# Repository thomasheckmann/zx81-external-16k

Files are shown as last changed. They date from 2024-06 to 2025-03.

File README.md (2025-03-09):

# zx81-external-16k
Simple and compact external 16K RAM interface for the ZX81 with WRX compability. The interface is made using THT components, making it easy for everyone to make. The interface for now is only using 16K from the 62256 memory chip, using the other half 16K might be added on later version. I might also consider making a SMD version, making it even smaller in size :-)

| SCHEMA | PCB |
| --- | --- |
|||

## version 1.0
The PCB arrived, so I populated it with some components (all written on the silkscreen).



BOM for v1.0 (16K only)
- LED 3mm
- Resistor 470 Ohm
- Resistor 4K7 Ohm
- 2 x Ceramic capacitor 100nF, P2,54
- 2 x Diode 1N4148
- 74LS00
- RAM 62256 or similar
- ZX81 Edge Connector or my [ZX81 Bus Extender](https://github.com/thomasheckmann/zx81-bus-extender)
  
NOTE: WRX hi-res, to get full support for hi-res WRX a cercamic capacitor is needed between PIN 20 (CS) and GND. In this build with a KM62256ALP-10 a 1,2nF ceramic capacitor should be fitted. 

The value for the capacitor for different 62256 SRAM chips tested with [STARFIGHT](https://problemkaputt.de/starfigh.htm)

- KM62256ALP-10, 1.2nF

## version 1.1 - full 32K support, with data in the 32-48K area.
Most version for internal 32K RAM puts the extra 16K at the top, 48 to 64K - but this is not what most 32K program expects. The 32K programs I have found expect the 32K from 16K, which requires some extra logic - another issue with this configuration is that normaly the ROM is mirrored between 32 and 48K, which means the ROM has to be disabled when the ZX81 access this part of the memory. I also decided to change the diodes from 1N4148 to BAT85 as suggested in general for this type of usage.

A little prototyping based on the v1.0 board - and yes, 32K from adress 16384 is all good here tested with Beamrider that require 32K and WRX :-)
| <!---> | <!---> |
| --- | --- |
|||

Programs tested with success so far:
- [Beamrider](https://problemkaputt.de/beamride.htm), 32K and WRX graphics 
- [MaxDemo](https://demozoo.org/productions/159644/), 32K and WRX graphics (impressive 320x240 resolution)
- [Cross Snake](https://github.com/Fabrizio-Caruso/CROSS-LIB/releases/tag/XSnake2.0), 32K and WRX
- [Cross Chase](https://github.com/Fabrizio-Caruso/CROSS-LIB/releases/tag/WRX), 32K and WRX
- [Space Invaders](https://splintergu.itch.io/space-invaders-for-zx81-wrx), 32K and WRX

32K Programs NOT working - as they require internal modification in order to run M/C above 32K area.
- [The Crystal Frog](https://www.sinclairzxworld.com/viewtopic.php?t=334)

| <!---> | <!---> |
| --- | --- |
|||

BOM for v1.1 (32K, continously from adress 16384)
- LED 3mm
- Resistor 470 Ohm
- Resistor 4K7 Ohm
- Resistor 10K Ohm
- 2 x Ceramic capacitor 100nF, P2,54
- 1 x Ceramic capacitor 1,2nF, P2,54
- 2 x Diode BAT85
- 74LS00
- 74LS32
- RAM 62256 or similar
- ZX81 Edge Connector or my [ZX81 Bus Extender](https://github.com/thomasheckmann/zx81-bus-extender)

The interface has been tested with the following 32K SRAM chips, all running Beamrider perfectly.
- UM62256E-70LL
- HM62256BLP-10
- AS6C62256-55PCN

### Test using SYSINFO.P v0.02
This test program examines the memory configuration and reports this, 32K ram starting from address 0x4000 :-)



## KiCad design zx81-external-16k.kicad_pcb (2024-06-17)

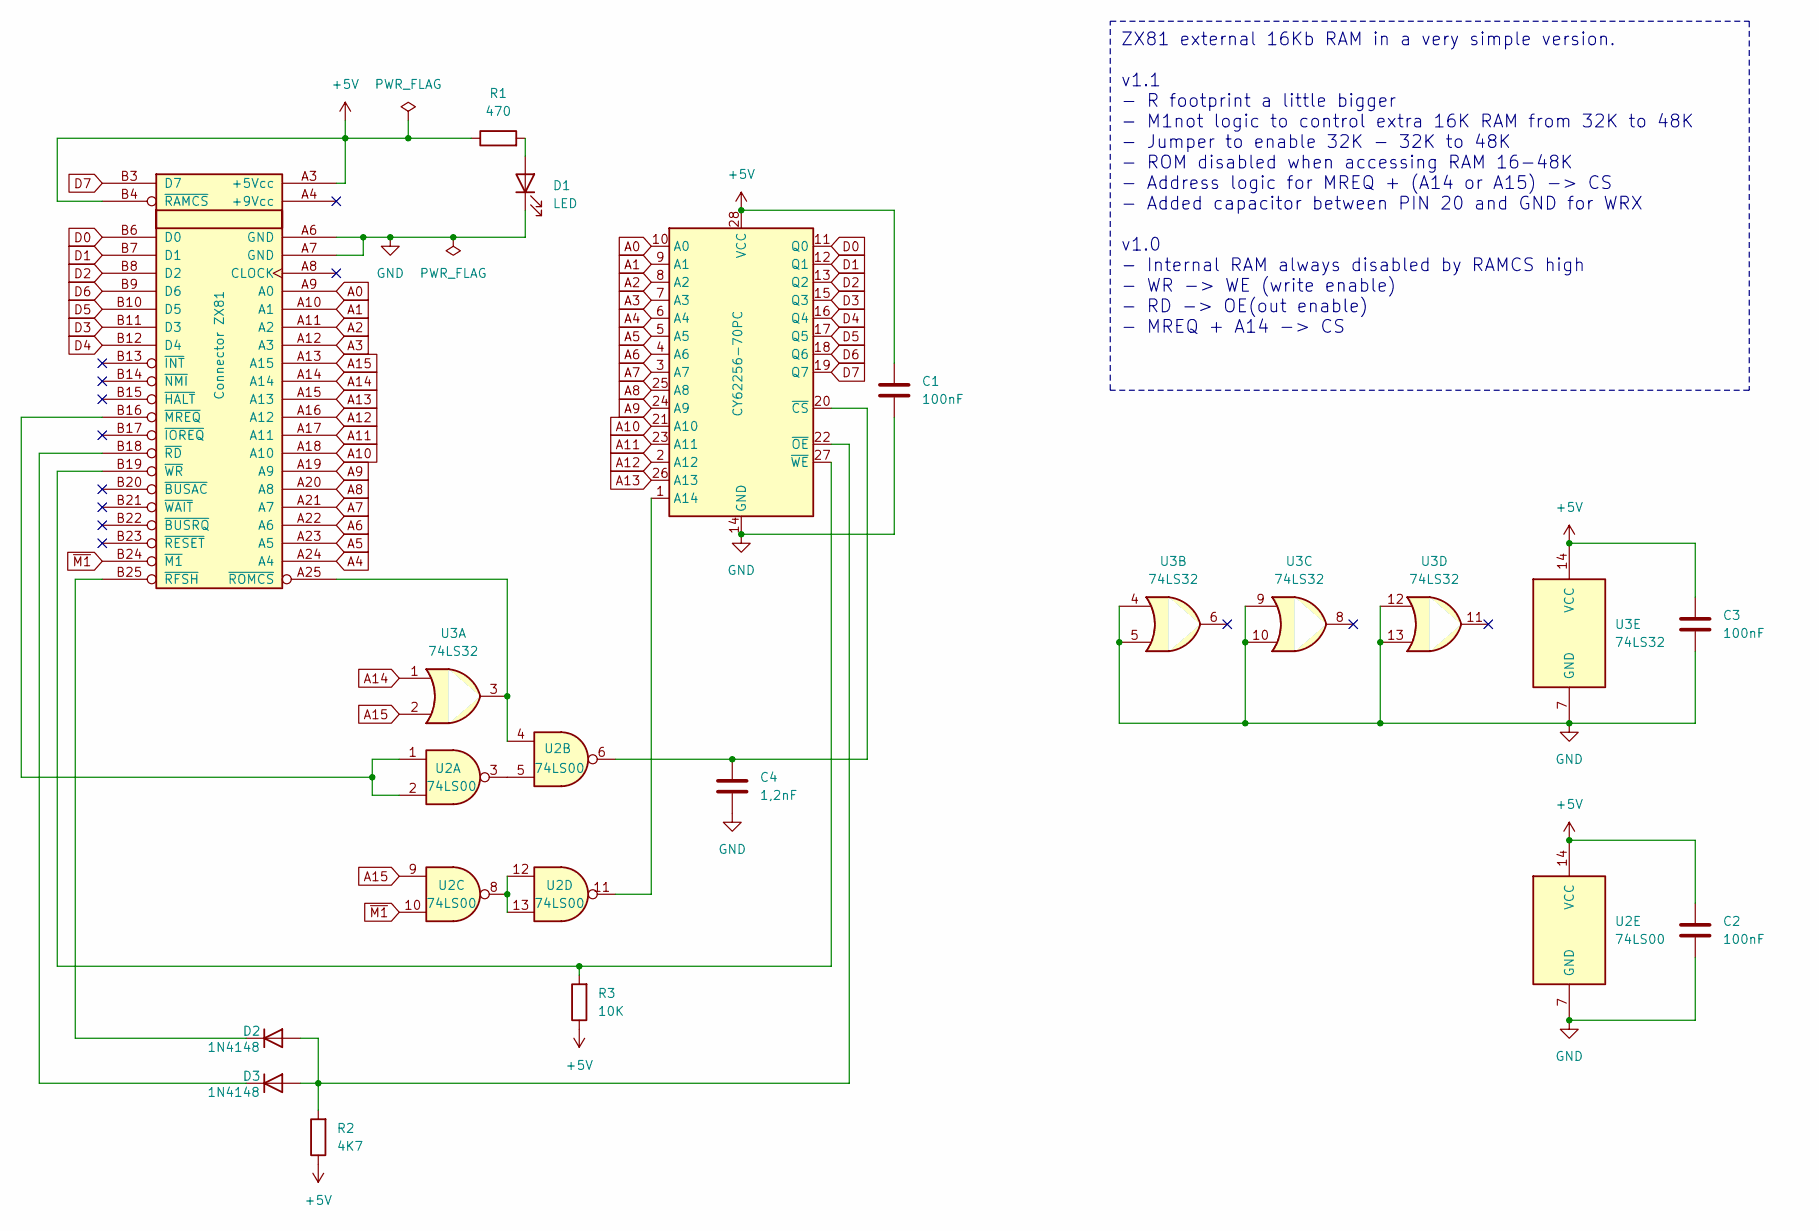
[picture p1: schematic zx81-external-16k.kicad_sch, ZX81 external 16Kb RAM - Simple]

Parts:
C1, C2, C3: 100nF; C_Disc_D3.0mm_W1.6mm_P2.50mm
C4: 1,2nF; C_Disc_D3.0mm_W1.6mm_P2.50mm
D1: LED; LED_D3.0mm
D2, D3: 1N4148; D_DO-35_SOD27_P7.62mm_Horizontal
J1: Connector ZX81; EDGE ZX81 BOTTOM
R1: 470; R_Axial_DIN0207_L6.3mm_D2.5mm_P10.16mm_Horizontal
R2: 4K7; R_Axial_DIN0207_L6.3mm_D2.5mm_P10.16mm_Horizontal
R3: 10K; R_Axial_DIN0207_L6.3mm_D2.5mm_P10.16mm_Horizontal
U1: CY62256-70PC; DIP-28_W15.24mm
U2: 74LS00; DIP-14_W7.62mm
U3: 74LS32; DIP-14_W7.62mm

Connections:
+5V: C1.1, C2.1, C3.1, J1.A3 (+5Vcc), J1.B4 (~RAMCS), R1.1, R2.1, R3.1, U1.28 (VCC), U2.14 (VCC), U3.14 (VCC)
A0: J1.A9 (A0), U1.10 (A0)
A1: J1.A10 (A1), U1.9 (A1)
A2: J1.A11 (A2), U1.8 (A2)
A3: J1.A12 (A3), U1.7 (A3)
A4: J1.A24 (A4), U1.6 (A4)
A5: J1.A23 (A5), U1.5 (A5)
A6: J1.A22 (A6), U1.4 (A6)
A7: J1.A21 (A7), U1.3 (A7)
A8: J1.A20 (A8), U1.25 (A8)
A9: J1.A19 (A9), U1.24 (A9)
A10: J1.A18 (A10), U1.21 (A10)
A11: J1.A17 (A11), U1.23 (A11)
A12: J1.A16 (A12), U1.2 (A12)
A13: J1.A15 (A13), U1.26 (A13)
A14: J1.A14, U3.1
A15: J1.A13 (A15), U2.9, U3.2
D0: J1.B6 (D0), U1.11 (Q0)
D1: J1.B7 (D1), U1.12 (Q1)
D2: J1.B8 (D2), U1.13 (Q2)
D3: J1.B11 (D3), U1.15 (Q3)
D4: J1.B12 (D4), U1.16 (Q4)
D5: J1.B10 (D5), U1.17 (Q5)
D6: J1.B9 (D6), U1.18 (Q6)
D7: J1.B3 (D7), U1.19 (Q7)
GND: C1.2, C2.2, C3.2, C4.2, D1.1 (K), J1.A6 (GND), J1.A7 (GND), U1.14 (GND), U2.7 (GND), U3.4, U3.5, U3.7 (GND), U3.9, U3.10, U3.12, U3.13
unnamed: D1.2 (A), R1.2
unnamed: D2.2 (A), D3.2 (A), R2.2, U1.22 (~OE)
unnamed: D2.1 (K), J1.B25 (~RFSH)
unnamed: D3.1 (K), J1.B18 (~RD)
unnamed: J1.B16 (~MREQ), U2.1, U2.2
unnamed: J1.A25 (~ROMCS), U2.4, U3.3
unnamed: J1.B19 (~WR), R3.2, U1.27 (~WE)
unnamed: U1.1 (A14), U2.11
unnamed: C4.1, U1.20 (~CS), U2.6
unnamed: U2.3, U2.5
unnamed: U2.8, U2.12, U2.13
~M1: J1.B24 (~M1), U2.10

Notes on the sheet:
ZX81 external 16Kb RAM in a very simple version. v1.1 - R footprint a little bigger - M1not logic to control extra 16K RAM from 32K to 48K - Jumper to enable 32K - 32K to 48K - ROM disabled when accessing RAM 16-48K - Address logic for MREQ + (A14 or A15) -> CS - Added capacitor between PIN 20 and 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

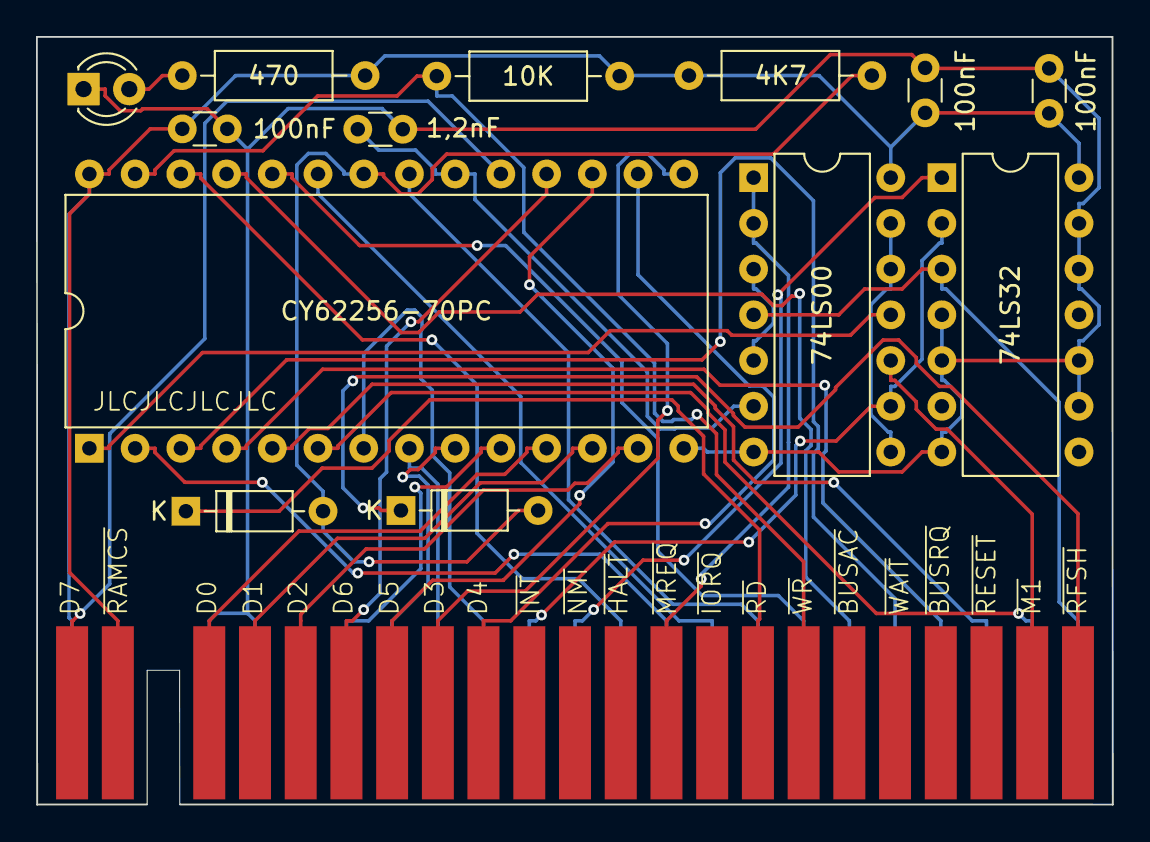
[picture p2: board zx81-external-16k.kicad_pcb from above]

Board: 2 copper layers, 59.8 x 42.7 mm, 14 parts (0 on the bottom side), 38 nets.

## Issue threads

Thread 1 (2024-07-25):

Standard connector compatibility

stevexyz, 2024-07-25:
Ciao Thomas,
I was looking at this nice interface, but for people to use it  would require another component to be attached to the standard ZX81.
I was thinking that if you make a design with holes for the standard connector you would have the compatibility with both options (current and standard connector). It is just an idea, feel free to close the issue and discard it in case.
To give you the idea I made the mockup picture attached.
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
PS: and please no SMD :)
Best!
_Stefano

thomasheckmann, 2024-07-27:
Thanks for your feedback, the original idea is to have either the standard connector or the pads to using my bus expander - as I understand it, you suggest having both connection options as the same time?

stevexyz, 2024-07-28:
Yes. As depicted probably is feasible with a single design

On Sat, Jul 27, 2024, 15:10 Thomas Heckmann ***@***.***>
wrote:

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
